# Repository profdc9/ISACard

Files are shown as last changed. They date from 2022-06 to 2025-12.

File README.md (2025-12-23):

# PC Storage Interface and Arduino Inteface

This is a simple card that provides two SD cards as mass storage devices on PC compatibles in an ISA slot.  This design is an adaptation of the Apple II version of the card (<https://www.github.com/profdc9/Apple2Card>).  For building in the future, it is designed to use only the most common chips: 74HCT32, 74HCT86, 28C64B/27C128/28C256, 82C55A, and ATMEGA328P.  It does not use Compactflash format as that is a rather uncommon memory card format at the time of this writing (Oct 2025).  The SD card interface is not as fast as a Compactflash card, however, being read through SPI.  Hopefully, the components to build this board will be available for many years to come to retro enthusiasts.

There is also a 10 pin SPI port to connect an external Wiznet 5500 Ethernet port.  A simple packet driver is written to interface this to the MSDOS TCP/IP stacks as described below.

The Arduino firmware (in the ISA2Arduino directory) communicates through the 8255 bidirectional parallel port to the ISA bus.  It can expose a SD card either as a single raw block device, or it can use an image file on a FAT16/32 filesystem on the SD card as the block device.  Block device image files are named `BLKDEVXX.IMG` where XX is a hexadecimal number between 01h and 0FFh denoting the file number.  The default (and fallback) is to use `BLKDEV01.IMG` on the SD card in SLOT 1 if it is formatted for a FAT FS.  There is a MSDOS COM file called "SETBLKDV" that sets the block device number to both SD slots, with the format being:

```shell
SETBLKDV <I/O address in hex> <block device number slot 1 in hex> <block device number slot 2 in hex>.
```

For example, to set the block device to 02h on slot 1 and 0Ch on slot 2, with the card being at I/O address 0330h:

```shell
SETBLKDV 330 02 0C
```

Block device number 00h is reserved for exposing the entire SD card as a raw block device (partition table and everything) to the host.  If you do not intend for the entire card to be usable and modifiable by the host, then do not choose this option.  Most modern SD cards have a very large capacity as compared to what MSDOS is designed to handle.  SD cards with up to 8.4 GB capacity can be accommodated by C/H/S addressing using 255 heads and 63 sectors, but larger cards can be accommodated only by LBA.  Therefore larger cards are likely only to be usable by FreeDOS or another operating system designed to handle that case.

The BIOS on the card is a modified version of the XT IDE Universal BIOS with a driver added for the SD card device.  It must be configured using the xtidecfg.com program as is required by other versions of the XT IDE Universal BIOS.  As a bonus, you get the other features of the XT IDE Universal BIOS as well, and it should support the other IDE devices already in the BIOS.  The card supports up to a 32 KB ROM, with the jumpers enabling 8K, 16K, or 32K ROM sizes.  Read only and writing may also be enabled for the EEPROM so that the flash utility may work.

As with other ISA cards that use a BIOS expansion ROM (<https://minuszerodegrees.net/rom/misc/ROM%20-%20BIOS%20expansion%20ROM.jpg>), a model IBM 5150 (original IBM PC) must have a 10/27/82 dated revision of the motherboard BIOS (<https://minuszerodegrees.net/5150/bios/5150_bios_revisions.htm>), or a Compaq Portable must have at least revision C of the motherboard BIOS.

The jumpers to set the BIOS location are labeled M13 to M17 on the board so that the ROM may be located to any 8k address in the upper 0C0000h to 0FFFFFh address space.  A shorted jumpered location indicates a zero bit, and an open jumper location is a one bit.  For example, address 0D0000h (the most common XT IDE Universal BIOS address) is M17, M15, M14, M13 shorted, and M16 open. Two jumpers enable the M13 and M14 address lines to be ignored so that a larger ROM may be used.  Similarly, the IO address is marked IO2 to IO9, which may be located at any multiple of four between 000h and 3FCh.  For the default address 330h, the jumpers are set to: IO7, IO6, IO3, IO2 shorted, IO9, IO8, IO5, IO4 open.  JP17 sets the ROM size to be 32K or 8K/16K, and JP19 sets the ROM size to be 8K or 16K.  JP18 sets the ROM to be read only or ready to be flashed.

There is an ICSP connect that may be used to flash the ATMEGA328P in situ.  Make sure any SD cards are removed from the slots before flashing!  JP10 must be jumpered to power the board with the programmer.

JP9 shorts out a diode that drops the voltage on the ATMEGA328P.  Usually JP9 should be present but may be removed if there are problems with some SD cards.  J4 is a debugging connector, and J3 is a connector intended to go to a Wiznet 5500 ethernet module through a 10 position IDC cable.

## Using the ethernet capability.

A common Wiznet W5500 adapter board can be connected to the PC card using a 10 pin IDC ribbon cable.  A photograph of this board is shown below.  This adapter board has a 10 pin header on it with a pinout that corresponds to a 10 pin header marked "EXTSPI/W5500" on the card.  A 10 pin IDC ribbon cable may be used to connect the two boards.  A DOS Ethernet packet driver has been written to allow a TCP/IP stack such as MTCP (<https://www.brutman.com/mTCP/>) to be used in MSDOS which this driver has been tested with.  This packet driver has the following invocation:

```shell
ISA5500 <Software IRQ> <Hardware IRQ> <I/O Address>.
```

For example, with a software IRQ of 0x60, hardware IRQ of 3, and an I/O address of 0x330, the invocation command is:

```shell
ISA5500 0x60 3 0x330
```

Because the ethernet and SD card share the same microcontroller, they can not be used simultaneously, and the drivers take turns between mass storage calls and ethernet calls.  In order to assemble the packet driver into a COM executable, you will need an assembler like Microsoft or Turbo assembler, and the  assemble source files from the packet driver distribution (PKTD11A.ZIP PKTD11B.ZIP PKTD11C.ZIP) (<http://crynwr.com/drivers/>).   You also need to add this to the Makefile:

```makefile
isa5500.com: head.obj isa5500.obj tail.obj
	$(LINK) head isa5500 tail,isa5500/m;
	exe2com isa5500
	del isa5500.exe
```

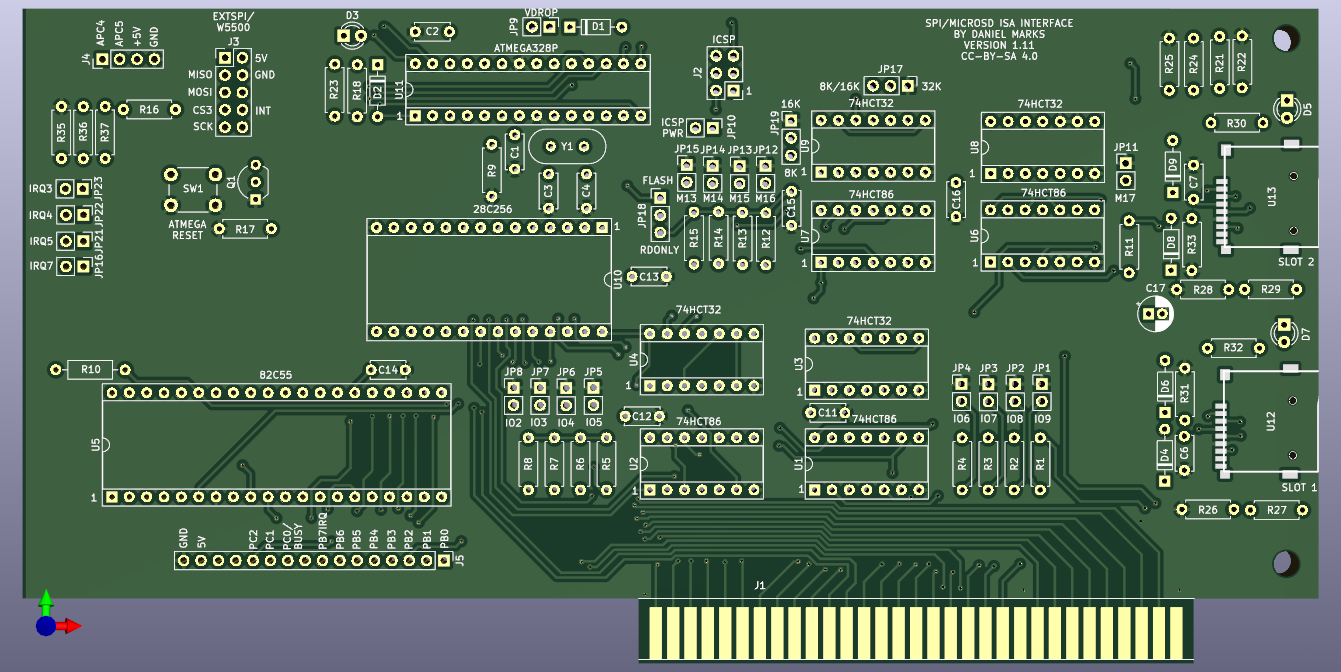
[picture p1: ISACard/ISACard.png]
ISACard


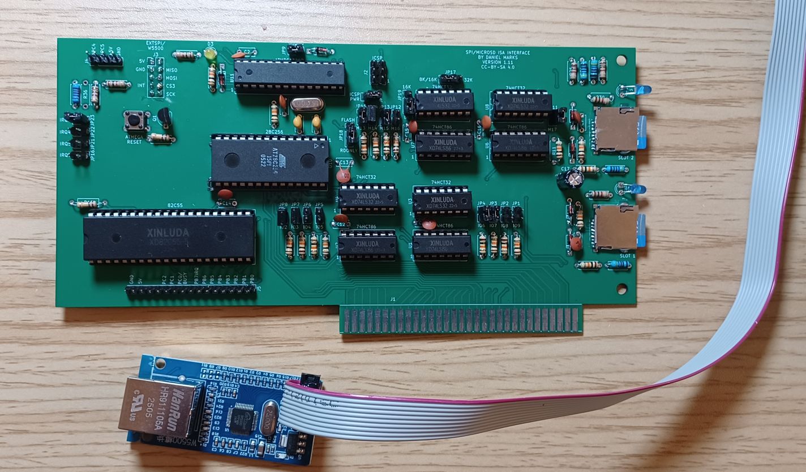
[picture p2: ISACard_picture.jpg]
ISACardPicture


## Licensing

The software derived from the GNU General Public License 2.0 (XT IDE Universal BIOS) is likewise licensed under the GNU General Public License 2.0 as required by the license with the modified source code being publically made available here on the GitHub.  Often software written by me is licensed under the zlib license.

The schematic designs (but not the circuit design itself) and the PCB layouts are copyrighted according to the Creative Commons 4.0 Attribution Share-Alike license.

None of these licenses should prevent anyone who wishes to reproduce this hardware and software and sell it from doing so, even for a profit.  However, source code modifications to the GPL licensed code must be made available with the product and likewise licensed under the GPLv2.

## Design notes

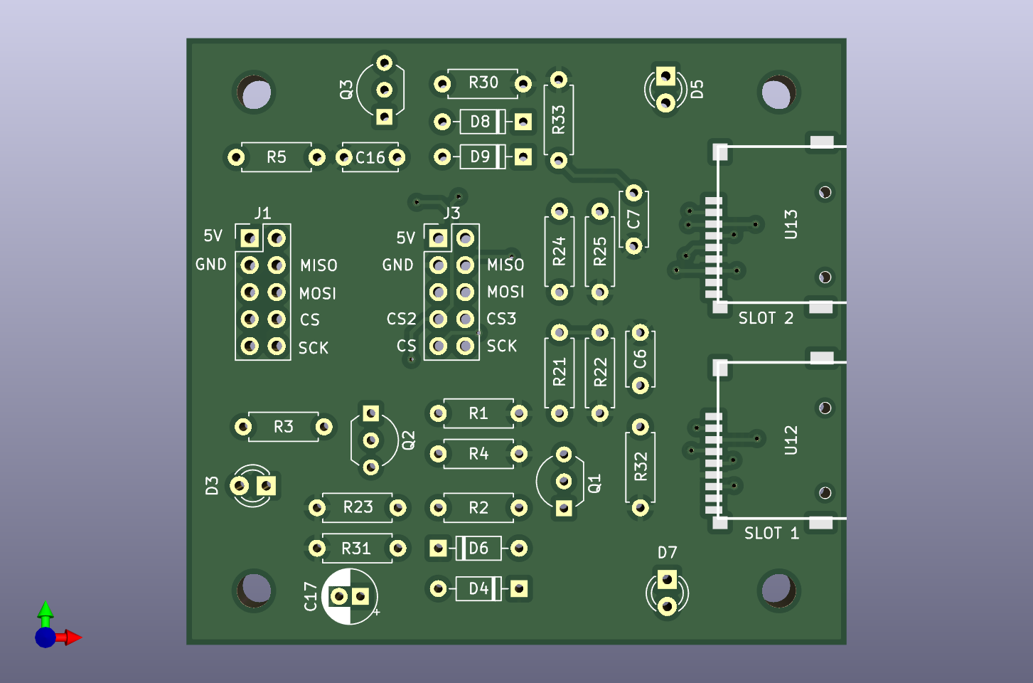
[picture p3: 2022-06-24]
ExtCard/ExtCard.png

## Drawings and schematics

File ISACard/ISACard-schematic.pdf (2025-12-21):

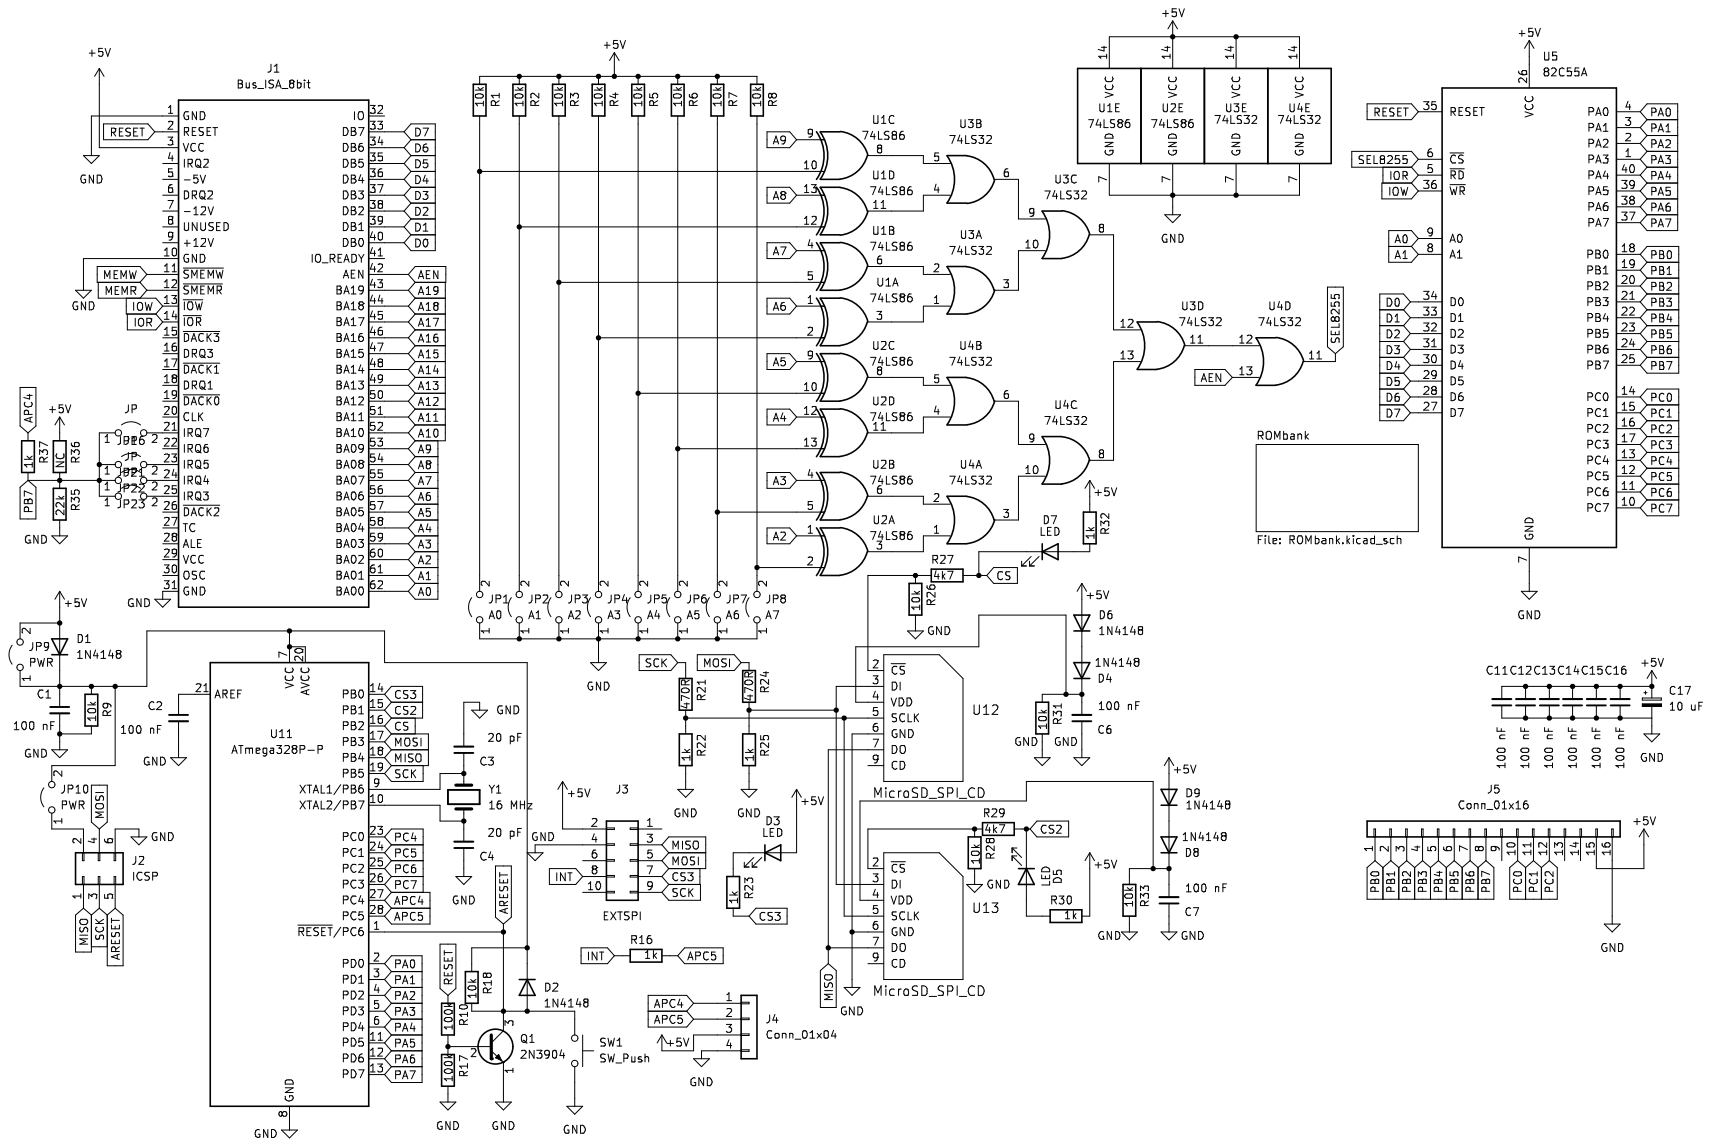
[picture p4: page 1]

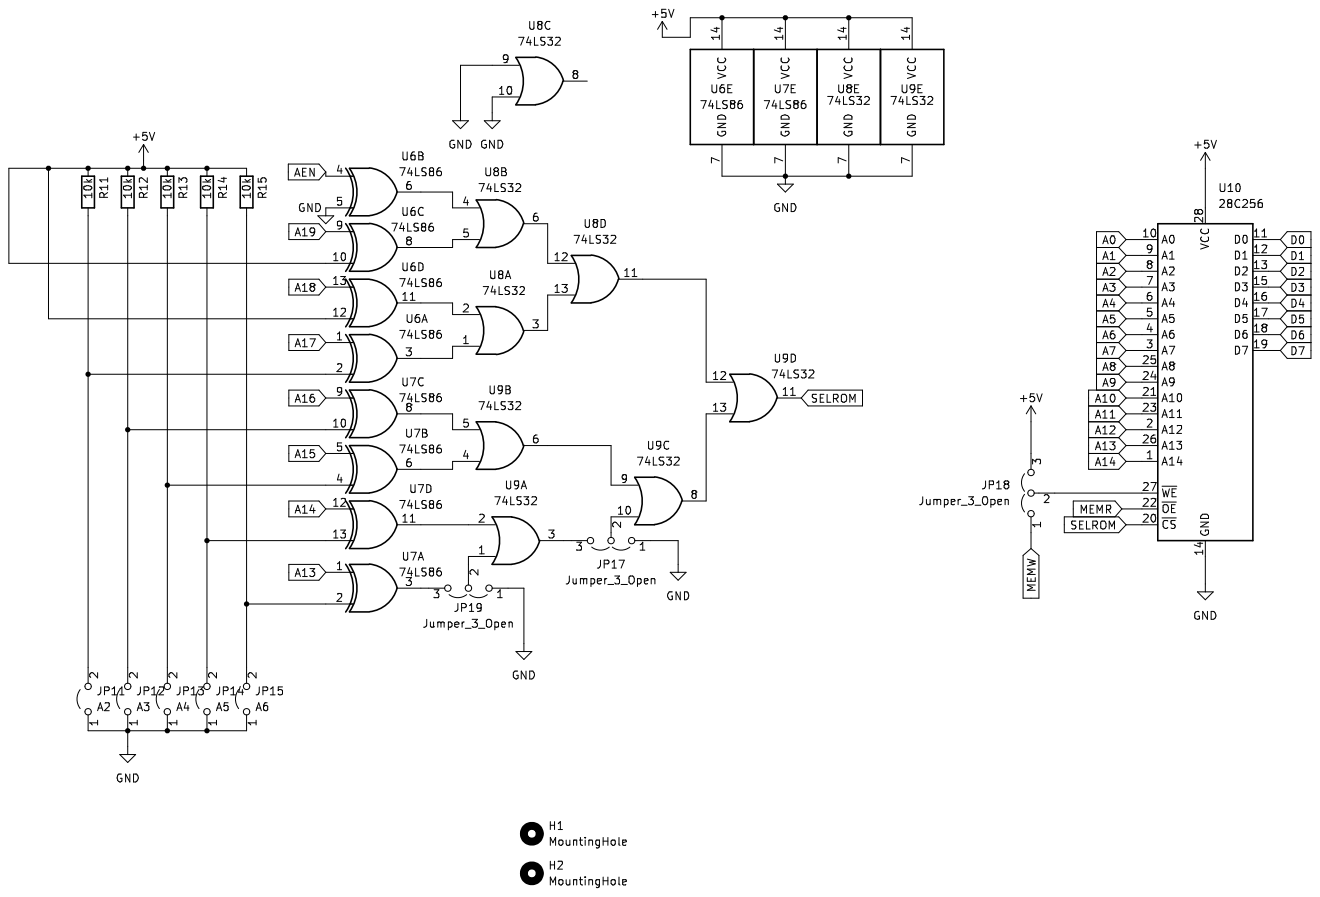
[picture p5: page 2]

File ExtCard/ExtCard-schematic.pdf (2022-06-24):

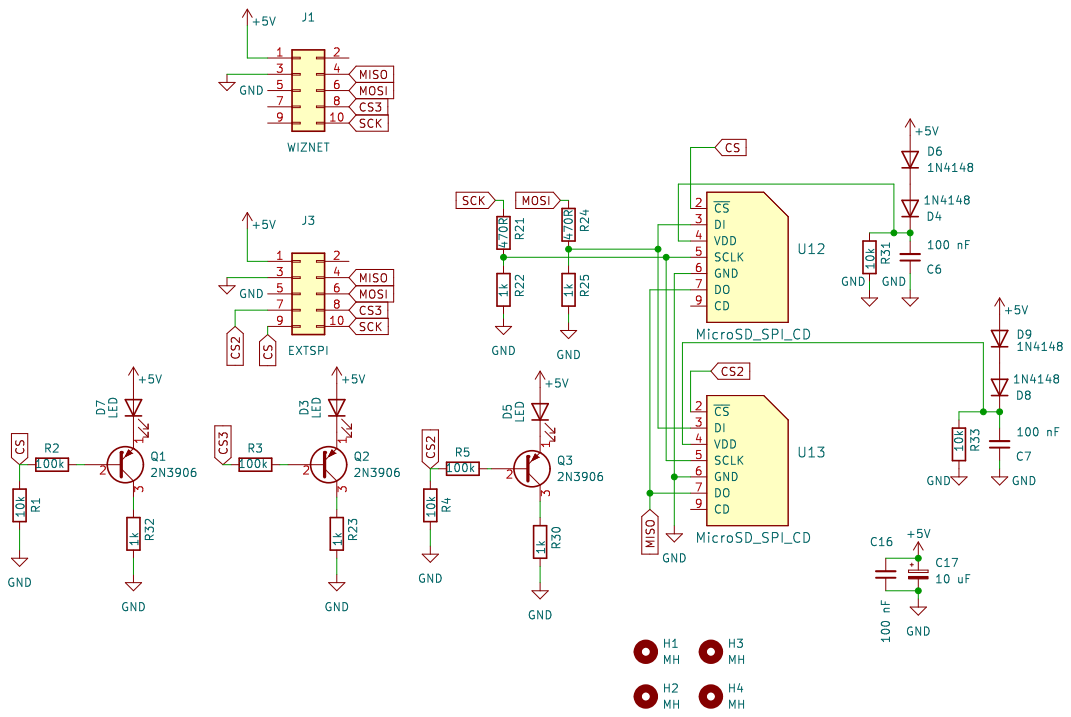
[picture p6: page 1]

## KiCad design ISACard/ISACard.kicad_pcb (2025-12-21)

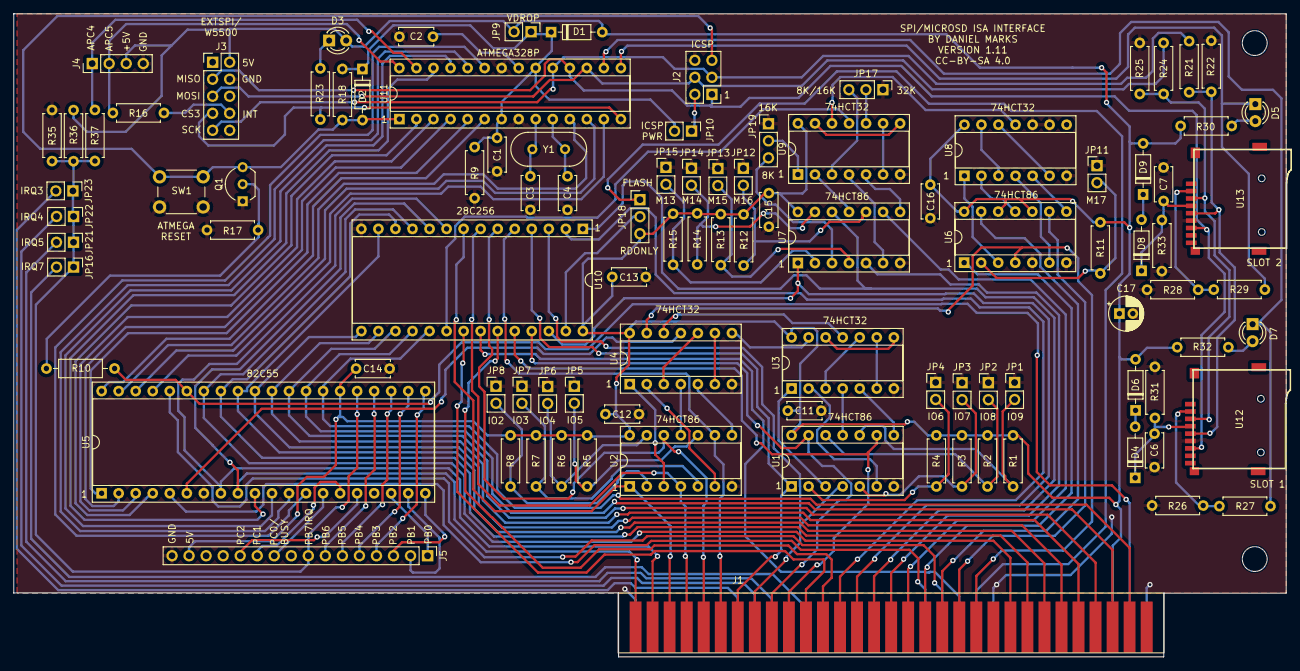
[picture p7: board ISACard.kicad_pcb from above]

Board: 2 copper layers, 189.7 x 95.9 mm, 101 parts (0 on the bottom side), 137 nets.

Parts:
C1, C2, C6, C7, C11, C12, C13, C14, C15, C16: 100 nF; C_Disc_D5.0mm_W2.5mm_P5.00mm
C3, C4: 20 pF; C_Disc_D5.0mm_W2.5mm_P5.00mm
C17: 10 uF; CP_Radial_D5.0mm_P2.00mm
D1, D2, D4, D6, D8, D9: 1N4148; D_DO-35_SOD27_P7.62mm_Horizontal
D3, D5, D7: LED; LED_D3.0mm
H1, H2: MountingHole; MountingHole_3.7mm
J1: Bus_ISA_8bit; BUS_ISA8
J2: ICSP; PinHeader_2x03_P2.54mm_Vertical
J3: EXTSPI; PinHeader_2x05_P2.54mm_Vertical
J4: Conn_01x04; PinHeader_1x04_P2.54mm_Vertical
J5: Conn_01x16; PinHeader_1x16_P2.54mm_Vertical
JP1: A0; PinHeader_1x02_P2.54mm_Vertical
JP2: A1; PinHeader_1x02_P2.54mm_Vertical
JP3, JP11: A2; PinHeader_1x02_P2.54mm_Vertical
JP4, JP12: A3; PinHeader_1x02_P2.54mm_Vertical
JP5, JP13: A4; PinHeader_1x02_P2.54mm_Vertical
JP6, JP14: A5; PinHeader_1x02_P2.54mm_Vertical
JP7, JP15: A6; PinHeader_1x02_P2.54mm_Vertical
JP8: A7; PinHeader_1x02_P2.54mm_Vertical
JP9, JP10: PWR; PinHeader_1x02_P2.54mm_Vertical
JP16, JP21, JP22, JP23: JP; PinHeader_1x02_P2.54mm_Vertical
JP17, JP18, JP19: Jumper_3_Open; PinHeader_1x03_P2.54mm_Vertical
Q1: 2N3904; TO-92_Inline_Wide
R1, R2, R3, R4, R5, R6, R7, R8, R9, R11, R12, R13, R14, R15, R18, R26, R28, R31, R33: 10k; R_Axial_DIN0207_L6.3mm_D2.5mm_P7.62mm_Horizontal
R10: 100k; R_Axial_DIN0207_L6.3mm_D2.5mm_P10.16mm_Horizontal
R16, R22, R23, R25, R30, R32, R37: 1k; R_Axial_DIN0207_L6.3mm_D2.5mm_P7.62mm_Horizontal
R17: 100k; R_Axial_DIN0207_L6.3mm_D2.5mm_P7.62mm_Horizontal
R21, R24: 470R; R_Axial_DIN0207_L6.3mm_D2.5mm_P7.62mm_Horizontal
R27, R29: 4k7; R_Axial_DIN0207_L6.3mm_D2.5mm_P7.62mm_Horizontal
R35: 22k; R_Axial_DIN0207_L6.3mm_D2.5mm_P7.62mm_Horizontal
R36: NC; R_Axial_DIN0207_L6.3mm_D2.5mm_P7.62mm_Horizontal
SW1: SW_Push; SW_PUSH_6mm
U1, U2, U6, U7: 74LS86; DIP-14_W7.62mm_Socket
U3, U4, U8, U9: 74LS32; DIP-14_W7.62mm_Socket
U5: 82C55A; DIP-40_W15.24mm_Socket
U10: 28C256; DIP-28_W15.24mm_Socket
U11: ATmega328P-P; DIP-28_W7.62mm_Socket
U12, U13: MicroSD_SPI_CD; GCT-MEM2055-00-190-01-A
Y1: 16 MHz; Crystal_HC49-U_Vertical

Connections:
+5V: C11.2, C12.2, C13.2, C14.2, C15.2, C16.2, C17.1, D1.2 (A), D3.2 (A), D6.2 (A), D9.2 (A), J1.3 (VCC), J3.2, J4.3, J5.15, JP9.2 (B), JP18.3 (B), R1.1, R2.1, R3.1, R4.1, R5.1, R6.1, R7.1, R8.1, R11.1, R12.1, R13.1, R14.1, R15.1, R30.2, R32.1, R36.1, U1.14 (VCC), U2.14 (VCC), U3.14 (VCC), U4.14 (VCC), U5.26 (VCC), U6.10, U6.12, U6.14 (VCC), U7.14 (VCC), U8.14 (VCC), U9.14 (VCC), U10.28 (VCC)
A0: J1.62 (BA00), U5.9 (A0), U10.10 (A0)
A1: J1.61 (BA01), U5.8 (A1), U10.9 (A1)
A2: J1.60 (BA02), U2.1, U10.8 (A2)
A3: J1.59 (BA03), U2.4, U10.7 (A3)
A4: J1.58 (BA04), U2.12, U10.6 (A4)
A5: J1.57 (BA05), U2.9, U10.5 (A5)
A6: J1.56 (BA06), U1.1, U10.4 (A6)
A7: J1.55 (BA07), U1.4, U10.3 (A7)
A8: J1.54 (BA08), U1.13, U10.25 (A8)
A9: J1.53 (BA09), U1.9, U10.24 (A9)
A10: J1.52 (BA10), U10.21 (A10)
A11: J1.51 (BA11), U10.23 (A11)
A12: J1.50 (BA12), U10.2 (A12)
A13: J1.49 (BA13), U7.1, U10.26 (A13)
A14: J1.48 (BA14), U7.12, U10.1 (A14)
A15: J1.47 (BA15), U7.5
A16: J1.46 (BA16), U7.9
A17: J1.45 (BA17), U6.1
A18: J1.44 (BA18), U6.13
A19: J1.43 (BA19), U6.9
AEN: J1.42 (AEN), U4.13, U6.4
APC4: J4.1, R37.1, U11.27 (PC4)
APC5: J4.2, R16.2, U11.28 (PC5)
ARESET: D2.2 (A), J2.5, Q1.3 (C), R18.2, SW1.1, U11.1 (~RESET/PC6)
CS: D7.1 (K), R27.2, U11.16 (PB2)
CS2: D5.1 (K), R29.2, U11.15 (PB1)
CS3: J3.7, R23.2, U11.14 (PB0)
D0: J1.40 (DB0), U5.34 (D0), U10.11 (D0)
D1: J1.39 (DB1), U5.33 (D1), U10.12 (D1)
D2: J1.38 (DB2), U5.32 (D2), U10.13 (D2)
D3: J1.37 (DB3), U5.31 (D3), U10.15 (D3)
D4: J1.36 (DB4), U5.30 (D4), U10.16 (D4)
D5: J1.35 (DB5), U5.29 (D5), U10.17 (D5)
D6: J1.34 (DB6), U5.28 (D6), U10.18 (D6)
D7: J1.33 (DB7), U5.27 (D7), U10.19 (D7)
GND: C1.2, C2.2, C3.2, C4.1, C6.1, C7.1, C11.1, C12.1, C13.1, C14.1, C15.1, C16.1, C17.2, J1.1 (GND), J1.10 (GND), J1.31 (GND), J2.6, J3.4, J4.4, J5.16, JP1.1 (A), JP2.1 (A), JP3.1 (A), JP4.1 (A), JP5.1 (A), JP6.1 (A), JP7.1 (A), JP8.1 (A), JP11.1 (A), JP12.1 (A), JP13.1 (A), JP14.1 (A), JP15.1 (A), JP17.1 (A), JP19.1 (A), Q1.1 (E), R9.2, R17.2, R22.2, R25.2, R26.2, R28.2, R31.2, R33.2, R35.2, SW1.2, U1.7 (GND), U2.7 (GND), U3.7 (GND), U4.7 (GND), U5.7 (GND), U6.5, U6.7 (GND), U7.7 (GND), U8.7 (GND), U8.9, U8.10, U9.7 (GND), U10.14 (GND), U11.8 (GND), U11.22 (GND), U12.6 (GND), U13.6 (GND)
INT: J3.8, R16.1
IOR: J1.14 (~IOR), U5.5 (~RD)
IOW: J1.13 (~IOW), U5.36 (~WR)
MEMR: J1.12 (~SMEMR), U10.22 (~OE)
MEMW: J1.11 (~SMEMW), JP18.1 (A)
MISO: J2.1, J3.3, U11.18 (PB4), U12.7 (DO), U13.7 (DO)
MOSI: J2.4, J3.5, R24.1, U11.17 (PB3)
unnamed: C1.1, D1.1 (K), D2.1 (K), JP9.1 (A), JP10.2 (B), R9.1, R18.1, U11.7 (VCC), U11.20 (AVCC)
unnamed: D3.1 (K), R23.1
unnamed: D4.2 (A), D6.1 (K)
unnamed: C6.2, D4.1 (K), R31.1, U12.4 (VDD)
unnamed: D5.2 (A), R30.1
unnamed: D7.2 (A), R32.2
unnamed: D8.2 (A), D9.1 (K)
unnamed: C7.2, D8.1 (K), R33.1, U13.4 (VDD)
unnamed: J1.25 (IRQ3), JP23.2 (B)
unnamed: J1.24 (IRQ4), JP22.2 (B)
unnamed: J1.23 (IRQ5), JP21.2 (B)
unnamed: J1.21 (IRQ7), JP16.2 (B)
unnamed: J2.2, JP10.1 (A)
unnamed: JP1.2 (B), R1.2, U1.10
unnamed: JP2.2 (B), R2.2, U1.12
unnamed: JP3.2 (B), R3.2, U1.5
unnamed: JP4.2 (B), R4.2, U1.2
unnamed: JP5.2 (B), R5.2, U2.10
unnamed: JP6.2 (B), R6.2, U2.13
unnamed: JP7.2 (B), R7.2, U2.5
unnamed: JP8.2 (B), R8.2, U2.2
unnamed: JP11.2 (B), R11.2, U6.2
unnamed: JP12.2 (B), R12.2, U7.10
unnamed: JP13.2 (B), R13.2, U7.4
unnamed: JP14.2 (B), R14.2, U7.13
unnamed: JP15.2 (B), R15.2, U7.2
unnamed: JP17.3 (B), U9.3
unnamed: JP17.2 (C), U9.10
unnamed: JP18.2 (C), U10.27 (~WE)
unnamed: JP19.3 (B), U7.3
unnamed: JP19.2 (C), U9.1
unnamed: Q1.2 (B), R10.2, R17.1
unnamed: U1.3, U3.1
unnamed: U1.6, U3.2
unnamed: U1.8, U3.5
unnamed: U1.11, U3.4
unnamed: U2.3, U4.1
unnamed: U2.6, U4.2
unnamed: U2.8, U4.5
unnamed: U2.11, U4.4
unnamed: U3.6, U3.9
unnamed: U3.3, U3.10
unnamed: U3.11, U4.12
unnamed: U3.8, U3.12
unnamed: U3.13, U4.8
unnamed: U4.6, U4.9
unnamed: U4.3, U4.10
unnamed: U6.3, U8.1
unnamed: U6.6, U8.4
unnamed: U6.8, U8.5
unnamed: U6.11, U8.2
unnamed: U7.6, U9.4
unnamed: U7.8, U9.5
unnamed: U7.11, U9.2
unnamed: U8.11, U9.12
unnamed: U8.6, U8.12
unnamed: U8.3, U8.13
unnamed: U9.6, U9.9
unnamed: U9.8, U9.13
unnamed: C2.1, U11.21 (AREF)
unnamed: C3.1, U11.9 (XTAL1/PB6), Y1.2
unnamed: C4.2, U11.10 (XTAL2/PB7), Y1.1
unnamed: R24.2, R25.1, U12.3 (DI), U13.3 (DI)
unnamed: R21.2, R22.1, U12.5 (SCLK), U13.5 (SCLK)
unnamed: R26.1, R27.1, U12.2 (~CS)
unnamed: R28.1, R29.1, U13.2 (~CS)
PA0: U5.4 (PA0), U11.2 (PD0)
PA1: U5.3 (PA1), U11.3 (PD1)
PA2: U5.2 (PA2), U11.4 (PD2)
PA3: U5.1 (PA3), U11.5 (PD3)
PA4: U5.40 (PA4), U11.6 (PD4)
PA5: U5.39 (PA5), U11.11 (PD5)
PA6: U5.38 (PA6), U11.12 (PD6)
PA7: U5.37 (PA7), U11.13 (PD7)
PB0: J5.1, U5.18 (PB0)
PB1: J5.2, U5.19 (PB1)
PB2: J5.3, U5.20 (PB2)
PB3: J5.4, U5.21 (PB3)
PB4: J5.5, U5.22 (PB4)
PB5: J5.6, U5.23 (PB5)
PB6: J5.7, U5.24 (PB6)
PB7: J5.8, JP16.1 (A), JP21.1 (A), JP22.1 (A), JP23.1 (A), R35.1, R36.2, R37.2, U5.25 (PB7)
PC0: J5.10, U5.14 (PC0)
PC1: J5.11, U5.15 (PC1)
PC2: J5.12, U5.16 (PC2)
PC4: U5.13 (PC4), U11.23 (PC0)
PC5: U5.12 (PC5), U11.24 (PC1)
PC6: U5.11 (PC6), U11.25 (PC2)
PC7: U5.10 (PC7), U11.26 (PC3)
RESET: J1.2 (RESET), R10.1, U5.35 (RESET)
SCK: J2.3, J3.9, R21.1, U11.19 (PB5)
SEL8255: U4.11, U5.6 (~CS)
SELROM: U9.11, U10.20 (~CS)

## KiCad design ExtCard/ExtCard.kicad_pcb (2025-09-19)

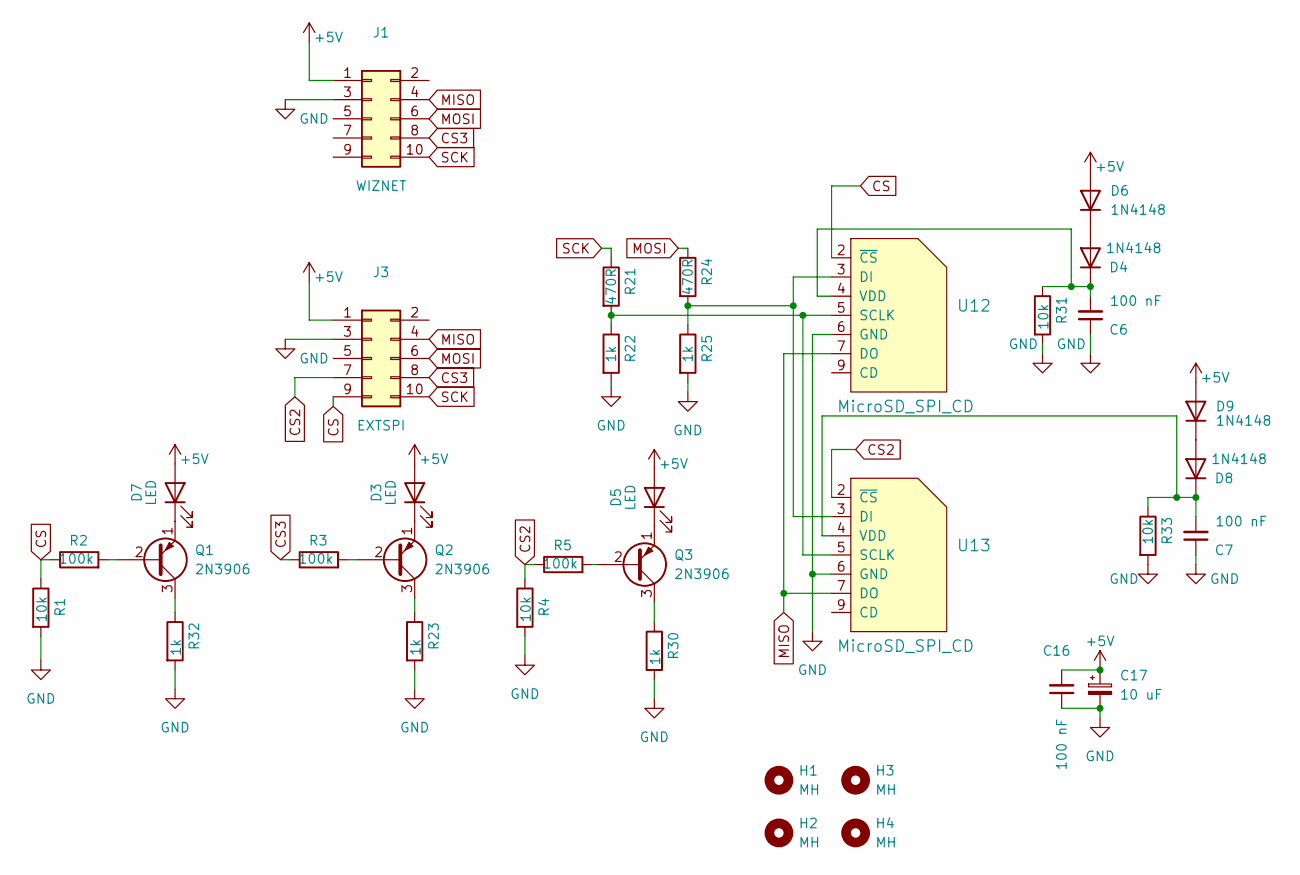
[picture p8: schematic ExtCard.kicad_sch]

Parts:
C6, C7, C16: 100 nF; C_Disc_D5.0mm_W2.5mm_P5.00mm
C17: 10 uF; CP_Radial_D5.0mm_P2.00mm
D3, D5, D7: LED; LED_D3.0mm
D4, D6, D8, D9: 1N4148; D_DO-35_SOD27_P7.62mm_Horizontal
H1, H2, H3, H4: MH; MountingHole_3.2mm_M3
J1: WIZNET; PinHeader_2x05_P2.54mm_Vertical
J3: EXTSPI; PinHeader_2x05_P2.54mm_Vertical
Q1, Q2, Q3: 2N3906; TO-92_Inline_Wide
R1, R4, R31, R33: 10k; R_Axial_DIN0207_L6.3mm_D2.5mm_P7.62mm_Horizontal
R2, R3, R5: 100k; R_Axial_DIN0207_L6.3mm_D2.5mm_P7.62mm_Horizontal
R21, R24: 470R; R_Axial_DIN0207_L6.3mm_D2.5mm_P7.62mm_Horizontal
R22, R23, R25, R30, R32: 1k; R_Axial_DIN0207_L6.3mm_D2.5mm_P7.62mm_Horizontal
U12, U13: MicroSD_SPI_CD; GCT-MEM2055-00-190-01-A

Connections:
+5V: C16.2, C17.1, D3.2 (A), D5.2 (A), D6.2 (A), D7.2 (A), D9.2 (A), J1.1, J3.1
CS: J3.9, R1.1, R2.1, U12.2 (~CS)
CS2: J3.7, R4.1, R5.1, U13.2 (~CS)
CS3: J1.8, J3.8, R3.1
GND: C6.1, C7.1, C16.1, C17.2, J1.3, J3.3, R1.2, R4.2, R22.2, R23.2, R25.2, R30.2, R31.2, R32.2, R33.2, U12.6 (GND), U13.6 (GND)
MISO: J1.4, J3.4, U12.7 (DO), U13.7 (DO)
MOSI: J1.6, J3.6, R24.1
unnamed: C6.2, D4.1 (K), R31.1, U12.4 (VDD)
unnamed: C7.2, D8.1 (K), R33.1, U13.4 (VDD)
unnamed: D4.2 (A), D6.1 (K)
unnamed: D5.1 (K), Q3.1 (E)
unnamed: D8.2 (A), D9.1 (K)
unnamed: D7.1 (K), Q1.1 (E)
unnamed: Q1.2 (B), R2.2
unnamed: Q1.3 (C), R32.1
unnamed: D3.1 (K), Q2.1 (E)
unnamed: Q2.2 (B), R3.2
unnamed: Q2.3 (C), R23.1
unnamed: Q3.2 (B), R5.2
unnamed: Q3.3 (C), R30.1
unnamed: R21.2, R22.1, U12.5 (SCLK), U13.5 (SCLK)
unnamed: R24.2, R25.1, U12.3 (DI), U13.3 (DI)
SCK: J1.10, J3.10, R21.1

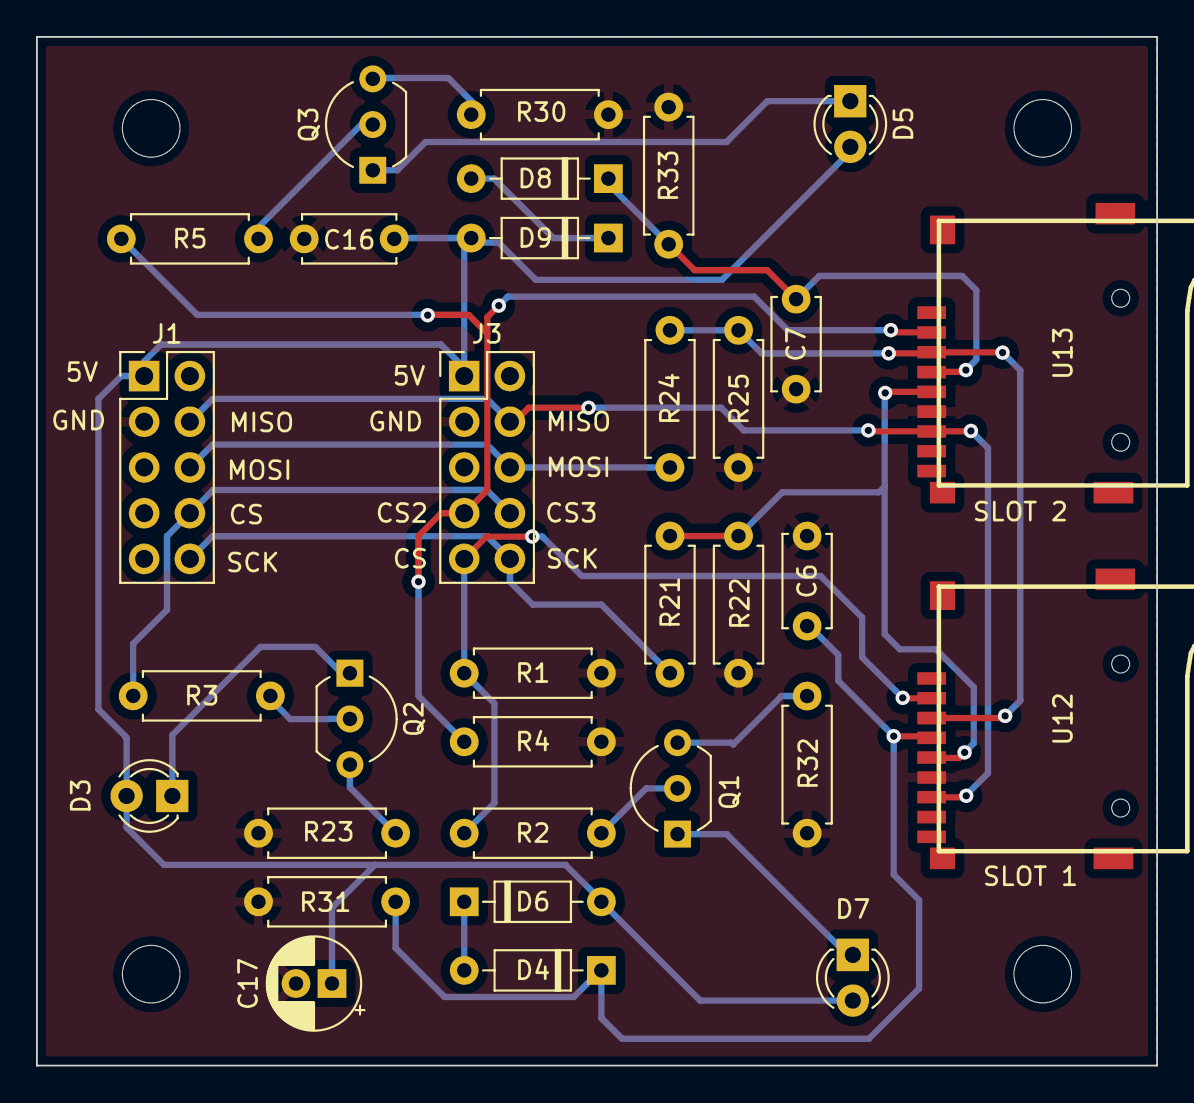
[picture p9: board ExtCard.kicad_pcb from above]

Board: 2 copper layers, 62.2 x 57.2 mm, 36 parts (0 on the bottom side), 23 nets.

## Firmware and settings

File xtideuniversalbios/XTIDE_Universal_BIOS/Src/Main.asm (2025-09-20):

; Project name	:	XTIDE Universal BIOS
; Authors		:	Tomi Tilli
;				:	aitotat@gmail.com
;				:
;				:	Greg Lindhorst
;				:	gregli@hotmail.com
;				;
;				:	Krister Nordvall
;				:	krille_n_@hotmail.com
;				:
; Description	:	Main file for BIOS. This is the only file that needs
;					to be compiled since other files are included to this
;					file (so no linker needed, Nasm does it all).

;
; XTIDE Universal BIOS and Associated Tools
; Copyright (C) 2009-2010 by Tomi Tilli, 2011-2013 by XTIDE Universal BIOS Team.
;
; This program is free software; you can redistribute it and/or modify
; it under the terms of the GNU General Public License as published by
; the Free Software Foundation; either version 2 of the License, or
; (at your option) any later version.
;
; This program is distributed in the hope that it will be useful,
; but WITHOUT ANY WARRANTY; without even the implied warranty of
; MERCHANTABILITY or FITNESS FOR A PARTICULAR PURPOSE.  See the
; GNU General Public License for more details.
; Visit http://www.gnu.org/licenses/old-licenses/gpl-2.0.html
;

	ORG 0							; Code start offset 0000h

	; We must define included libraries before including "AssemblyLibrary.inc".
%define	EXCLUDE_FROM_XUB					; Exclude unused library functions
%ifdef MODULE_BOOT_MENU
	%define MENUEVENT_INLINE_OFFSETS		; Only one menu required, save space and inline offsets
	%define INCLUDE_MENU_LIBRARY
	%define MENU_NO_ESC						; User cannot 'esc' out of the menu
%else	; If no boot menu included
	%define	INCLUDE_DISPLAY_LIBRARY
	%define INCLUDE_KEYBOARD_LIBRARY
	%define INCLUDE_TIME_LIBRARY
%endif


	; Included .inc files
	%include "AssemblyLibrary.inc"	; Assembly Library. Must be included first!
	%include "ModuleDependency.inc"	; Dependency checks for optional modules. Must be included second!
	%include "Version.inc"
	%include "ATA_ID.inc"			; For ATA Drive Information structs
	%include "IdeRegisters.inc"		; For ATA Registers, flags and commands
	%include "Int13h.inc"			; Equates for INT 13h functions
	%include "CustomDPT.inc"		; For Disk Parameter Table
	%include "RomVars.inc"			; For ROMVARS and IDEVARS structs
	%include "RamVars.inc"			; For RAMVARS struct
	%include "BootVars.inc"			; For BOOTVARS struct
	%include "IdeIO.inc"			; Macros for IDE port I/O
	%include "DeviceIDE.inc"		; For IDE device equates



; Section containing code
SECTION .text

; ROM variables (must start at offset 0)
CNT_ROM_BLOCKS		EQU		BIOS_SIZE / 512		; number of 512B blocks, 16 = 8kB BIOS
istruc ROMVARS
	at	ROMVARS.wRomSign,	dw	0AA55h			; PC ROM signature
	at	ROMVARS.bRomSize,	db	CNT_ROM_BLOCKS	; ROM size in 512B blocks
	at	ROMVARS.rgbJump,	jmp	Initialize_FromMainBiosRomSearch
	at	ROMVARS.rgbSign,	db	FLASH_SIGNATURE
	at	ROMVARS.szTitle,	db	TITLE_STRING
	at	ROMVARS.szVersion,	db	ROM_VERSION_STRING

;---------------------------;
; AT Build default settings ;
;---------------------------;
%ifdef USE_AT
%ifdef USE_386
	at	ROMVARS.wFlags,			dw	FLG_ROMVARS_FULLMODE | FLG_ROMVARS_CLEAR_BDA_HD_COUNT | MASK_ROMVARS_INCLUDED_MODULES
%else
	at	ROMVARS.wFlags,			dw	FLG_ROMVARS_FULLMODE | MASK_ROMVARS_INCLUDED_MODULES
%endif
	at	ROMVARS.wDisplayMode,	dw	DEFAULT_TEXT_MODE
%ifdef MODULE_BOOT_MENU
	at	ROMVARS.wBootTimeout,	dw	BOOT_MENU_DEFAULT_TIMEOUT
	at	ROMVARS.pColorTheme,	dw	ColorTheme				; Offset to the ATTRIBUTE_CHARS struc that holds the color theme
%endif
	at	ROMVARS.bIdeCnt,		db	2						; Number of supported controllers
	at	ROMVARS.bBootDrv,		db	80h						; Boot Menu default drive
	at	ROMVARS.bMinFddCnt, 	db	0						; Do not force minimum number of floppy drives
	at	ROMVARS.bStealSize,		db	1						; Steal 1kB from base memory
	at	ROMVARS.bIdleTimeout,	db	0						; Standby timer disabled by default

	at	ROMVARS.ideVars0+IDEVARS.wBasePort,			dw	DEVICE_ATA_PRIMARY_PORT 		; Controller Command Block base port
	at	ROMVARS.ideVars0+IDEVARS.wControlBlockPort,	dw	DEVICE_ATA_PRIMARY_PORTCTRL 	; Controller Control Block base port
	at	ROMVARS.ideVars0+IDEVARS.bDevice,			db	DEVICE_16BIT_ATA
	at	ROMVARS.ideVars0+IDEVARS.bIRQ,				db	14
	at	ROMVARS.ideVars0+IDEVARS.drvParamsMaster+DRVPARAMS.wFlags,	dw	DISABLE_WRITE_CACHE | FLG_DRVPARAMS_BLOCKMODE | (TRANSLATEMODE_AUTO<<TRANSLATEMODE_FIELD_POSITION)
	at	ROMVARS.ideVars0+IDEVARS.drvParamsSlave+DRVPARAMS.wFlags,	dw	DISABLE_WRITE_CACHE | FLG_DRVPARAMS_BLOCKMODE | (TRANSLATEMODE_AUTO<<TRANSLATEMODE_FIELD_POSITION)

	at	ROMVARS.ideVars1+IDEVARS.wBasePort,			dw	DEVICE_ATA_SECONDARY_PORT
	at	ROMVARS.ideVars1+IDEVARS.wControlBlockPort,	dw	DEVICE_ATA_SECONDARY_PORTCTRL
	at	ROMVARS.ideVars1+IDEVARS.bDevice,			db	DEVICE_16BIT_ATA
	at	ROMVARS.ideVars1+IDEVARS.bIRQ,				db	15
	at	ROMVARS.ideVars1+IDEVARS.drvParamsMaster+DRVPARAMS.wFlags,	dw	DISABLE_WRITE_CACHE | FLG_DRVPARAMS_BLOCKMODE | (TRANSLATEMODE_AUTO<<TRANSLATEMODE_FIELD_POSITION)
	at	ROMVARS.ideVars1+IDEVARS.drvParamsSlave+DRVPARAMS.wFlags,	dw	DISABLE_WRITE_CACHE | FLG_DRVPARAMS_BLOCKMODE | (TRANSLATEMODE_AUTO<<TRANSLATEMODE_FIELD_POSITION)

	at	ROMVARS.ideVars2+IDEVARS.wBasePort,			dw	DEVICE_ATA_TERTIARY_PORT
	at	ROMVARS.ideVars2+IDEVARS.wControlBlockPort,	dw	DEVICE_ATA_TERTIARY_PORTCTRL
	at	ROMVARS.ideVars2+IDEVARS.bDevice,			db	DEVICE_16BIT_ATA
	at	ROMVARS.ideVars2+IDEVARS.bIRQ,				db	0	; Should be 11 on the GSI Inc. Model 2C
	at	ROMVARS.ideVars2+IDEVARS.drvParamsMaster+DRVPARAMS.wFlags,	dw	DISABLE_WRITE_CACHE | FLG_DRVPARAMS_BLOCKMODE | (TRANSLATEMODE_AUTO<<TRANSLATEMODE_FIELD_POSITION)
	at	ROMVARS.ideVars2+IDEVARS.drvParamsSlave+DRVPARAMS.wFlags,	dw	DISABLE_WRITE_CACHE | FLG_DRVPARAMS_BLOCKMODE | (TRANSLATEMODE_AUTO<<TRANSLATEMODE_FIELD_POSITION)

	at	ROMVARS.ideVars3+IDEVARS.wBasePort,			dw	DEVICE_ATA_QUATERNARY_PORT
	at	ROMVARS.ideVars3+IDEVARS.wControlBlockPort,	dw	DEVICE_ATA_QUATERNARY_PORTCTRL
	at	ROMVARS.ideVars3+IDEVARS.bDevice,			db	DEVICE_16BIT_ATA
	at	ROMVARS.ideVars3+IDEVARS.bIRQ,				db	0	; Should be 10 on the GSI Inc. Model 2C
	at	ROMVARS.ideVars3+IDEVARS.drvParamsMaster+DRVPARAMS.wFlags,	dw	DISABLE_WRITE_CACHE | FLG_DRVPARAMS_BLOCKMODE | (TRANSLATEMODE_AUTO<<TRANSLATEMODE_FIELD_POSITION)
	at	ROMVARS.ideVars3+IDEVARS.drvParamsSlave+DRVPARAMS.wFlags,	dw	DISABLE_WRITE_CACHE | FLG_DRVPARAMS_BLOCKMODE | (TRANSLATEMODE_AUTO<<TRANSLATEMODE_FIELD_POSITION)

%ifdef MODULE_SERIAL
	at	ROMVARS.ideVarsSerialAuto+IDEVARS.bDevice,	db	DEVICE_SERIAL_PORT
%endif
%else
;-----------------------------------;
; XT and XT+ Build default settings ;
;-----------------------------------;
	at	ROMVARS.wFlags,			dw	MASK_ROMVARS_INCLUDED_MODULES
	at	ROMVARS.wDisplayMode,	dw	DEFAULT_TEXT_MODE
%ifdef MODULE_BOOT_MENU
	at	ROMVARS.wBootTimeout,	dw	BOOT_MENU_DEFAULT_TIMEOUT
	at	ROMVARS.pColorTheme,	dw	ColorTheme				; Offset to the ATTRIBUTE_CHARS struc that holds the color theme
%endif
	at	ROMVARS.bIdeCnt,		db	1
	at	ROMVARS.bBootDrv,		db	80h						; Boot Menu default drive
	at	ROMVARS.bMinFddCnt, 	db	0						; Do not force minimum number of floppy drives
	at	ROMVARS.bStealSize,		db	1						; Steal 1kB from base memory in full mode
	at	ROMVARS.bIdleTimeout,	db	0						; Standby timer disabled by default

%ifndef MODULE_8BIT_IDE
	at	ROMVARS.ideVars0+IDEVARS.wBasePort,			dw	DEVICE_ATA_PRIMARY_PORT 		; Controller Command Block base port
	at	ROMVARS.ideVars0+IDEVARS.wControlBlockPort,	dw	DEVICE_ATA_PRIMARY_PORTCTRL 	; Controller Control Block base port
	at	ROMVARS.ideVars0+IDEVARS.bDevice,			db	DEVICE_16BIT_ATA
%elifdef MODULE_8BIT_IDE_ADVANCED
	at	ROMVARS.ideVars0+IDEVARS.wBasePort,			dw	DEVICE_XTIDE_DEFAULT_PORT		; Controller Command Block base port
	at	ROMVARS.ideVars0+IDEVARS.bDevice,			db	DEVICE_8BIT_XTCF_PIO8
%else
	at	ROMVARS.ideVars0+IDEVARS.wBasePort,			dw	DEVICE_XTIDE_DEFAULT_PORT		; Controller Command Block base port
	at	ROMVARS.ideVars0+IDEVARS.wControlBlockPort,	dw	DEVICE_XTIDE_DEFAULT_PORTCTRL	; Controller Control Block base port
	at	ROMVARS.ideVars0+IDEVARS.bDevice,			db	DEVICE_8BIT_XTIDE_REV1
%endif
	at	ROMVARS.ideVars0+IDEVARS.drvParamsMaster+DRVPARAMS.wFlags,	db	DISABLE_WRITE_CACHE | FLG_DRVPARAMS_BLOCKMODE | (TRANSLATEMODE_AUTO<<TRANSLATEMODE_FIELD_POSITION)
	at	ROMVARS.ideVars0+IDEVARS.drvParamsSlave+DRVPARAMS.wFlags,	db	DISABLE_WRITE_CACHE | FLG_DRVPARAMS_BLOCKMODE | (TRANSLATEMODE_AUTO<<TRANSLATEMODE_FIELD_POSITION)

	at	ROMVARS.ideVars1+IDEVARS.wBasePort,			dw	DEVICE_ATA_SECONDARY_PORT
	at	ROMVARS.ideVars1+IDEVARS.wControlBlockPort,	dw	DEVICE_ATA_SECONDARY_PORTCTRL
	at	ROMVARS.ideVars1+IDEVARS.bDevice,			db	DEVICE_16BIT_ATA
	at	ROMVARS.ideVars1+IDEVARS.drvParamsMaster+DRVPARAMS.wFlags,	db	DISABLE_WRITE_CACHE | FLG_DRVPARAMS_BLOCKMODE | (TRANSLATEMODE_AUTO<<TRANSLATEMODE_FIELD_POSITION)
	at	ROMVARS.ideVars1+IDEVARS.drvParamsSlave+DRVPARAMS.wFlags,	db	DISABLE_WRITE_CACHE | FLG_DRVPARAMS_BLOCKMODE | (TRANSLATEMODE_AUTO<<TRANSLATEMODE_FIELD_POSITION)

	at	ROMVARS.ideVars2+IDEVARS.wBasePort,			dw	DEVICE_ATA_TERTIARY_PORT
	at	ROMVARS.ideVars2+IDEVARS.wControlBlockPort,	dw	DEVICE_ATA_TERTIARY_PORTCTRL
	at	ROMVARS.ideVars2+IDEVARS.bDevice,			db	DEVICE_16BIT_ATA
	at	ROMVARS.ideVars2+IDEVARS.drvParamsMaster+DRVPARAMS.wFlags,	db	DISABLE_WRITE_CACHE | FLG_DRVPARAMS_BLOCKMODE | (TRANSLATEMODE_AUTO<<TRANSLATEMODE_FIELD_POSITION)
	at	ROMVARS.ideVars2+IDEVARS.drvParamsSlave+DRVPARAMS.wFlags,	db	DISABLE_WRITE_CACHE | FLG_DRVPARAMS_BLOCKMODE | (TRANSLATEMODE_AUTO<<TRANSLATEMODE_FIELD_POSITION)

	at	ROMVARS.ideVars3+IDEVARS.wBasePort,			dw	DEVICE_ATA_QUATERNARY_PORT
	at	ROMVARS.ideVars3+IDEVARS.wControlBlockPort,	dw	DEVICE_ATA_QUATERNARY_PORTCTRL
	at	ROMVARS.ideVars3+IDEVARS.bDevice,			db	DEVICE_16BIT_ATA
	at	ROMVARS.ideVars3+IDEVARS.drvParamsMaster+DRVPARAMS.wFlags,	db	DISABLE_WRITE_CACHE | FLG_DRVPARAMS_BLOCKMODE | (TRANSLATEMODE_AUTO<<TRANSLATEMODE_FIELD_POSITION)
	at	ROMVARS.ideVars3+IDEVARS.drvParamsSlave+DRVPARAMS.wFlags,	db	DISABLE_WRITE_CACHE | FLG_DRVPARAMS_BLOCKMODE | (TRANSLATEMODE_AUTO<<TRANSLATEMODE_FIELD_POSITION)

%ifdef MODULE_SERIAL
	at	ROMVARS.ideVarsSerialAuto+IDEVARS.bDevice,	db	DEVICE_SERIAL_PORT
%endif
%endif
iend

	; Strings are first to avoid them moving unnecessarily when code is turned on and off with %ifdef's
	; since some groups of strings need to be on the same 256-byte page.
	;
%ifdef MODULE_STRINGS_COMPRESSED
	%define STRINGSCOMPRESSED_STRINGS
	%include "StringsCompressed.asm"
%else
	%include "Strings.asm"			; For BIOS message strings
%endif

	; Libraries, data, Initialization and drive detection

	%include "AssemblyLibrary.asm"
%ifdef MODULE_WIN9X_CMOS_HACK
	%include "CMOS.asm"				; This belongs in the Assembly Library
%endif

	; String compression tables need to come after the AssemblyLibrary (since they depend on addresses
	; established in the assembly library), and are unnecessary if strings are not compressed.
	;
%ifdef MODULE_STRINGS_COMPRESSED
	%undef  STRINGSCOMPRESSED_STRINGS
	%define STRINGSCOMPRESSED_TABLES
	%include "StringsCompressed.asm"
%endif

	%include "Initialize.asm"		; For BIOS initialization
	%include "Interrupts.asm"		; For Interrupt initialization
	%include "RamVars.asm"			; For RAMVARS initialization and access
	%include "BootVars.asm"			; For initializing variables used during init and boot
	%include "FloppyDrive.asm"		; Floppy Drive related functions
	%include "CreateDPT.asm"		; For creating DPTs
	%include "FindDPT.asm"			; For finding DPTs
	%include "AccessDPT.asm"		; For accessing DPTs
	%include "AtaGeometry.asm"		; For generating L-CHS parameters
	%include "DrvDetectInfo.asm"	; For creating DRVDETECTINFO structs
	%include "AtaID.asm"			; For ATA Identify Device information
	%include "DetectDrives.asm"		; For detecting IDE drives
	%include "DetectPrint.asm"		; For printing drive detection strings
%ifdef MODULE_COMPATIBLE_TABLES
	%include "CompatibleDPT.asm"
%endif

	; Hotkey Bar
%ifdef MODULE_HOTKEYS
	%include "HotkeyBar.asm"		; For hotkeys during drive detection and boot menu
%endif
%ifdef MODULE_DRIVEXLATE
	%include "DriveXlate.asm"		; For swapping drive numbers, must come immediately after HotkeyBar.asm
%endif

	; Boot menu
%ifdef MODULE_BOOT_MENU
	%include "BootMenu.asm"			; For Boot Menu operations
	%include "BootMenuEvent.asm"	; For menu library event handling
									; NOTE: BootMenuPrint needs to come immediately after BootMenuEvent
									;       so that jump table entries in BootMenuEvent stay within 8-bits
	%include "BootMenuPrint.asm"	; For printing Boot Menu strings, also includes "BootMenuPrintCfg.asm"
%endif

	; Boot loader
%ifdef MODULE_VERY_LATE_INIT
	%include "Int13hBiosInit.asm"
%endif
	%include "Int19h.asm"			; For Int 19h, Boot Loader
	%include "BootSector.asm"		; For loading boot sector
	%include "Int19hReset.asm"		; INT 19h handler for proper system reset

	; For all device types
	%include "Idepack.asm"
	%include "Device.asm"
	%include "Timer.asm"			; For timeout and delay

	; IDE Device support
%ifdef MODULE_ADVANCED_ATA
	%include "AdvAtaInit.asm"		; For initializing VLB and PCI controllers
	%include "Vision.asm"			; QDI Vision QD6500 and QD6580 support
	%include "PDC20x30.asm"			; Promise PDC 20230-C and 20630 support
%endif
	%include "IdeCommand.asm"
%ifdef MODULE_8BIT_IDE_ADVANCED
	%include "JrIdeTransfer.asm"	; Must be included after IdeCommand.asm
	%include "IdeDmaBlock.asm"
%endif
	%include "IdeTransfer.asm"
	%include "IdePioBlock.asm"
	%include "IdeWait.asm"
	%include "IdeError.asm"			; Must be included after IdeWait.asm
	%include "IdeDPT.asm"
	%include "IdeIO.asm"
%ifdef MODULE_IRQ
	%include "IdeIrq.asm"
%endif

	; Serial Device support
%ifdef MODULE_SERIAL				; Serial Port Device support
	%include "SerialCommand.asm"
	%include "SerialDPT.asm"
%endif

	; SD Device support
%ifdef MODULE_SERIAL				; SD support
	%include "SDCommand.asm"
	%include "SDDPT.asm"
%endif

	; INT 13h Hard Disk BIOS functions
%ifdef MODULE_MFM_COMPATIBILITY
	%include "Int13hMFMcompatibility.asm"
%endif
	%include "Int13h.asm"			; For Int 13h, Disk functions
	%include "AH0h_HReset.asm"
	%include "AH1h_HStatus.asm"
	%include "AH2h_HRead.asm"
	%include "AH3h_HWrite.asm"
	%include "AH4h_HVerify.asm"
	%include "AH8h_HParams.asm"
	%include "AH9h_HInit.asm"
	%include "AHCh_HSeek.asm"
	%include "AH10h_HReady.asm"
	%include "AH11h_HRecal.asm"
	%include "AH15h_HSize.asm"
%ifdef MODULE_8BIT_IDE_ADVANCED
	%include "AH1Eh_XTCF.asm"
%endif
	%include "AH23h_HFeatures.asm"
	%include "AH24h_HSetBlocks.asm"
	%include "AH25h_HDrvID.asm"
	%include "Address.asm"			; For sector address translations
	%include "Prepare.asm"			; For buffer pointer normalization
%ifdef MODULE_EBIOS
	%include "AH42h_ExtendedReadSectors.asm"
	%include "AH43h_ExtendedWriteSectors.asm"
	%include "AH44h_ExtendedVerifySectors.asm"
	%include "AH47h_ExtendedSeek.asm"
	%include "AH48h_GetExtendedDriveParameters.asm"
	%include "AH41h_CheckIfExtensionsPresent.asm"
%endif


%ifndef CHECK_FOR_UNUSED_ENTRYPOINTS
; Although it's very unlikely to happen, we give warnings for builds that cannot be automatically checksummed due to the size being too large.
; In some cases it's theoretically possible to checksum the build anyway (manually) which is why these are warnings and not errors.
%if BIOS_SIZE = 8192				; A small build, possibly a candidate for the ROM socket on a 3Com 3C503 card.
	%if ($-$$) <= BIOS_SIZE			; Only give warnings when the problem isn't obvious anyway.
		%if ($-$$) > BIOS_SIZE - 3
			%warning "This build is too large to be auto-checksummed!"
		%endif
	%endif
%elif ($-$$) = BIOS_SIZE			; A large or tiny build.
	%warning "This build is too large to be auto-checksummed!"
%endif
%endif

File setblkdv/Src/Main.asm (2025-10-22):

;
;   Copyright (c) 2025 Daniel Marks
;
;  This software is provided 'as-is', without any express or implied
;  warranty. In no event will the authors be held liable for any damages
;  arising from the use of this software.
;
;  Permission is granted to anyone to use this software for any purpose,
;  including commercial applications, and to alter it and redistribute it
;  freely, subject to the following restrictions:
;
;  1. The origin of this software must not be misrepresented; you must not
;   claim that you wrote the original software. If you use this software
;   in a product, an acknowledgment in the product documentation would be
;   appreciated but is not required.
;  2. Altered source versions must be plainly marked as such, and must not be
;   misrepresented as being the original software.
;  3. This notice may not be removed or altered from any source distribution.
;
; Section containing code

ORG		100h

SECTION .text

SD_8255_Port_A							EQU		0
SD_8255_Port_B							EQU		1
SD_8255_Port_C							EQU		2
SD_8255_Control_Port					EQU		3

Start:
	jmp		Main_Start

;-------------------------------------------------------------------
UseSplashQuit:
	mov		dx, UseSplash
	mov		ah, 09h
	int		021h
	mov 	ax, 04C01h		; Errorlevel 1 in AL
	int		021h

;-------------------------------------------------------------------
Read_Hex:
	xor		dx,dx
.Read_Digit:
	mov		al,[bx]
	cmp		al,'0'
	jc		SHORT .EndDig
	cmp		al,'9'+1
	jc		SHORT .ShiftDigit
	or		al,020h
	cmp		al,'a'
	jc		SHORT .EndDig
	cmp		al,'f'+1
	jnc		SHORT .EndDig
	sub		al,'a'-10
.ShiftDigit:
	and		al,0fh
	shl		dx,1
	shl		dx,1
	shl		dx,1
	shl		dx,1
	or		dl,al
	inc		bx
	jmp		SHORT .Read_Digit
.EndDig:
	ret

Write_Hex:
	push	cx
	mov		cx,2
.Write_Digit:
	mov		al,dl
	shr		al,1
	shr		al,1
	shr		al,1
	shr		al,1
	shl		dl,1
	shl		dl,1
	shl		dl,1
	shl		dl,1
	cmp		al,10
	jc		SHORT .NoCap
	add		al,'A'-'9'-1
.NoCap:
	add		al,'0'
	push	dx
	mov		dl,al
	mov		ah,02h
	int		021h
	pop		dx
	loop	.Write_Digit
	pop		cx
	ret

Skip_Spaces:
	mov		al,[bx]
	cmp		al,' '
	jnz		.EndSpace
	inc		bx
	jmp		SHORT Skip_Spaces
.EndSpace:
	ret

SmallDelay:
	push	cx
	mov		cx,[slowness]
.SmallDelay2:
	loop	.SmallDelay2
	pop		cx
	ret

;-------------------------------------------------------------------
; Port output timeout
; Outputs a byte to the 8255
;	Parameters
;		DX:		Port Number Base
;		AL:		Byte to output
;	Returns
;		CF:		Cleared if outputted, set if timed out
;	Corrupts registers
;		AL
SDOutTimeout:
	push	dx
	push	cx
	xor		cx,cx
	add		dl,SD_8255_Port_A
	out		dx,al
	add		dl,(SD_8255_Port_C-SD_8255_Port_A)
.SDOutTimeout1:
	in		al,dx
	test	al,080h
	jnz		SHORT .SDOutTimeoutRecv
	call	SmallDelay
	loop	.SDOutTimeout1
	stc
.SDOutTimeout2:
	pop		cx
	pop		dx
	ret
.SDOutTimeoutRecv:
	clc
	jmp		SHORT .SDOutTimeout2

;-------------------------------------------------------------------
; Port input timeout
; Outputs a byte to the 8255
;	Parameters
;		DX:		Port Number Base
;	Returns
;		CF:		Cleared if byte received, set if timed out
;		AL:		Byte input (if one is received)
SDInTimeout:
	push	dx
	push	cx
	xor		cx,cx
	add		dl,SD_8255_Port_C
.SDInTimeout1:
	in		al,dx
	test	al,020h
	jnz		SHORT .SDInTimeoutRecv
	call	SmallDelay
	loop	.SDInTimeout1
	stc
	jmp		SHORT SDOutTimeout.SDOutTimeout2
.SDInTimeoutRecv:
	sub		dl,(SD_8255_Port_C-SD_8255_Port_A)
	in		al,dx
	clc
	jmp		SHORT SDOutTimeout.SDOutTimeout2

;-------------------------------------------------------------------
; SDServer_CheckPort
; Checks for a 8255 and responding microcontroller on port DX
;	Parameters:
;		DX:		Port Number Base   
;	Returns:
;		CF:		Cleared if success, set if error
;	Corrupts registers:
;		AX
SDServer_CheckPort:
	and		dl,0FCh
	add		dl,SD_8255_Control_Port
	mov		al,0FAh
	out		dx,al		; initialize 8255 mode 2
	mov		al,01h
	out		dx,al		; C0=1 interrupt routine shouldnt interfere
	sub		dl,SD_8255_Control_Port

	push	cx
	mov		cx,16			; Try ring up byte sixteen times
.SDServer_CheckPort1:
	mov		al,0eeh
	call	SDOutTimeout		; Output a byte
	jc		SHORT .SDServer_NextIter
	call	SDInTimeout			; Input the response
	jc		SHORT .SDServer_NextIter
	cmp		al,047h				; Return this byte on success
	jnz		SHORT .SDServer_NextIter

	mov		al,0edh
	call	SDOutTimeout		; Output a byte
	jc		SHORT .SDServer_NextIter
	call	SDInTimeout			; Input the response
	jc		SHORT .SDServer_NextIter
	cmp		al,09Ch				; Return this byte on success
	jz		SHORT .SDServer_CheckPort2

.SDServer_NextIter:
	loop	.SDServer_CheckPort1
	pop		cx					; Did not get a response
	stc
	ret
.SDServer_CheckPort2:
	pop		cx
	clc
	ret

ErrorSplash:
	jmp		UseSplashQuit

;--------------------------------------------------------------------
; Program start
;--------------------------------------------------------------------
Main_Start:
	mov		WORD [skipprogram],1

	mov		bx,081h
	call	Skip_Spaces
	mov		al,[bx]
	cmp		al,0dh
	jz		SHORT ErrorSplash
	call	Read_Hex
	mov		[ioPortAddress],dx
	call	Skip_Spaces
	mov		al,[bx]
	cmp		al,0dh
	jz		SHORT .QueryPort
	call	Read_Hex
	mov		[blkDevCard0],dx
	call	Skip_Spaces
	mov		al,[bx]
	cmp		al,0dh
	jz		SHORT ErrorSplash
	call	Read_Hex
	mov		[blkDevCard1],dx
	call	Skip_Spaces
	mov		al,[bx]
	cmp		al,0dh
	jnz		SHORT ErrorSplash

	mov		WORD [skipprogram],0

	mov		dx, BlkDevSplash
	mov		ah, 09h
	int		021h

	mov		dl, [ioPortAddress+1]
	call	Write_Hex
	mov		dl, [ioPortAddress]
	call	Write_Hex

	mov		dx, BlkDevSplash2
	mov		ah, 09h
	int		021h
	mov		dl, [blkDevCard0]
	call	Write_Hex

	mov		dx, BlkDevSplash3
	mov		ah, 09h
	int		021h
	mov		dl, [blkDevCard1]
	call	Write_Hex

.QueryPort:
	mov		WORD [slowness],1
	mov		dx,[ioPortAddress]
	call	SDServer_CheckPort
	jnc		.FoundPort

	mov		dx, PortNotFound
	mov		ah, 09h
	int		021h
	jmp		.ExitToDOS

.FoundPort:
	mov		WORD [slowness],100

	cmp		WORD [skipprogram],0
	jnz		SHORT .SkipWrite
	mov		al,081h			; set volume
	call	SDOutTimeout
	jc		.CmdError
	mov		al,[blkDevCard0]
	call	SDOutTimeout
	jc		.CmdError
	mov		al,[blkDevCard1]
	call	SDOutTimeout
	jc		.CmdError
	call	SDInTimeout
	jc		.CmdError
	cmp		al,081h
	jnz		.CmdError

.SkipWrite:
	mov		al,082h			; get volume to check
	call	SDOutTimeout
	jc		.CmdError
	call	SDInTimeout
	jc		.CmdError
	mov		[blkDevCard0SetVal],al
	call	SDInTimeout
	jc		.CmdError
	mov		[blkDevCard1SetVal],al
	call	SDInTimeout
	jc		.CmdError
	cmp		al,082h
	jnz		.CmdError

	mov		dx, SetToMsg
	mov		ah, 09h
	int		021h
	mov		dl, [blkDevCard0SetVal]
	call	Write_Hex
	mov		dx, BlkDevSplash3
	mov		ah, 09h
	int		021h
	mov		dl, [blkDevCard1SetVal]
	call	Write_Hex

	mov		dx, LFMessage
	mov		ah, 09h
	int		021h

	cmp		WORD [skipprogram],0
	jnz		SHORT .ExitToDOS

	mov		dx, RebootMsg
	mov		ah, 09h
	int		021h

.ExitToDOS:
	; Exit to DOS
	mov		dx, [ioPortAddress]
	and		dl,0FCh
	add		dl,SD_8255_Control_Port
	mov		al,0h
	out		dx,al			; Set C0=0 to say interrupts are OK again
	mov 	ax, 04C00h		; Errorlevel 0 in AL
	int		021h

.CmdError:
	mov		dx,CommandErrorMessage
	mov		ah, 09h
	int		021h
	jmp		SHORT	.ExitToDOS

; Section containing initialized data
SECTION .data
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

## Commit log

2022-06-23 Added labels
    [ISACard.kicad_pcb]
2022-06-23 Added gerber files and CS/CS2 to feature connector
    [ISACard-B_Cu.gbr, ISACard-B_Mask.gbr, ISACard-B_Silkscreen.gbr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]
2022-06-24 Added external SD card board
    [ExtCard-B_Cu.gbr, ExtCard-B_Mask.gbr, ExtCard-B_Silkscreen.gbr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]
2022-06-24 Moved around some traces
    [ExtCard-B_Cu.gbr, ExtCard-B_Mask.gbr, ExtCard-B_Silkscreen.gbr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]
2022-07-08 Added 16k/32k jumper
    [ExtCard-B_Cu.gbr, ExtCard-B_Mask.gbr, ExtCard-B_Silkscreen.gbr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]
2025-09-19 working on xt ide universal bios mod
    [ExtCard-B_Cu.gbr, ExtCard-B_Mask.gbr, ExtCard-B_Silkscreen.gbr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]
2025-09-24 Fixed some problems with the card...
    [ISACard-B_Cu.gbr, ISACard-B_Mask.gbr, ISACard-B_Silkscreen.gbr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]
2025-09-24 Rearranged the order of the logic
    [ISACard-B_Cu.gbr, ISACard-B_Mask.gbr, ISACard-B_Silkscreen.gbr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]
2025-09-26 fixed rom labels
    [ISACard-B_Cu.gbr, ISACard-B_Mask.gbr, ISACard-B_Silkscreen.gbr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]
2025-09-29 first commit ISA2Arduino
    [fuses.cfg]
2025-10-03 added documentation
    [ISACard-B_Cu.gbr, ISACard-B_Mask.gbr, ISACard-B_Silkscreen.gbr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]
2025-10-06 moved SD card slots to edge
    [ISACard.kicad_pcb, ROMbank.kicad_sch]
2025-10-06 Moved ATMEGA328P so that trace length is shorter
    [ISACard-B_Cu.gbr, ISACard-B_Mask.gbr, ISACard-B_Silkscreen.gbr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]
2025-10-08 minor pcb tweaks
    [ISACard-B_Cu.gbr, ISACard-B_Mask.gbr, ISACard-B_Silkscreen.gbr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]
2025-10-14 Added IRQ connection to ethernet
    [ISACard-B_Cu.gbr, ISACard-B_Mask.gbr, ISACard-B_Silkscreen.gbr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]
2025-10-14 Adjusted bias of resistors
    [ISACard-B_Cu.gbr, ISACard-B_Mask.gbr, ISACard-B_Silkscreen.gbr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]
2025-10-21 modified IRQ system
    [ISACard-B_Cu.gbr, ISACard-B_Mask.gbr, ISACard-B_Silkscreen.gbr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]
2025-10-22 Added C0 bit set for interrupt tracking
2025-10-22 Added IRQ response bit to determine spurious interrupt
    [ISACard-B_Cu.gbr, ISACard-B_Mask.gbr, ISACard-B_Silkscreen.gbr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]
2025-11-18 Send to JLCPCB
    [ISACard-B_Cu.gbr, ISACard-B_Mask.gbr, ISACard-B_Silkscreen.gbr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]
2025-12-20 First version of packet driver
    [ISACard-B_Cu.gbr, ISACard-B_Mask.gbr, ISACard-B_Silkscreen.gbr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]
2025-12-21 ISACard modification
    [ISACard-B_Cu.gbr, ISACard-B_Mask.gbr, ISACard-B_Silkscreen.gbr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]
2025-12-21 Double directory
    [ISACard-B_Cu.gbr, ISACard-B_Mask.gbr, ISACard-B_Silkscreen.gbr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]

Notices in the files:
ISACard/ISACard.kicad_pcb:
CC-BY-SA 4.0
